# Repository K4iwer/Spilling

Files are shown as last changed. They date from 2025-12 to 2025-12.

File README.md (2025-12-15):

# Spilling 

**Spilling** (uma junção de "Spinning" e "Feeling") é um jogo sério híbrido (físico e digital) desenvolvido para auxiliar no desenvolvimento socioemocional e cognitivo de crianças com Transtorno do Espectro Autista (TEA).

Este projeto foi desenvolvido como parte da disciplina **PCS3645 - Laboratório Digital II** da Escola Politécnica da USP.

## Propósito do Projeto

A proposta central do Spilling é utilizar uma interface tangível para ensinar como personagens reagem a diferentes objetos e situações, transformando conceitos abstratos de empatia e causalidade em uma interação física concreta.

O jogo visa:
* **Estimular a Empatia:** A criança deve deduzir emoções baseadas em contexto.
* **Reforço Positivo:** O sistema prioriza o incentivo e evita punições, mantendo o engajamento.
* **Tangibilidade:** O uso de controles físicos promove a coordenação motora fina e oferece uma noção concreta de causa e efeito.

## Como Funciona

O sistema opera através da integração entre uma aplicação de software e uma estrutura de hardware (controlada por uma FPGA).

1.  **Lógica:** O jogo apresenta "equações emocionais" (ex: *Menino + Sorvete = Feliz*), imagens com contextos e "equações emocionais" omitindo elementos.
2.  **Interface Física:** O jogador utiliza suportes físicos para selecionar o Personagem, a Situação e a Emoção. Sensores de distância leem a escolha e enviam para o software.
3.  **Feedback:** A tela exibe animações de sucesso ou encorajamento, e a estrutura física responde girando discos para confirmar a seleção.

### A Interface Digital

A aplicação foi desenvolvida em **Python** utilizando a biblioteca **PyQt6**. Ela possui um design limpo, com cores suaves para evitar sobrecarga sensorial.

Funcionalidades da interface:
* **Menu Principal:** Opções para Iniciar Jogo, Configurar Porta Serial (para conexão com a FPGA), Tutorial e Personalização de Cor de Fundo.
* **Fases Progressivas:** 12 níveis que evoluem de associação direta para inferência lógica.
* **Feedback Visual:** Telas de vitória e mensagens de apoio ("Quase lá") em caso de erro.

---

## Imagens

### Estrutura Física
*(A estrutura conta com discos giratórios e base para seleção de peças via sensores ultrassônicos)*

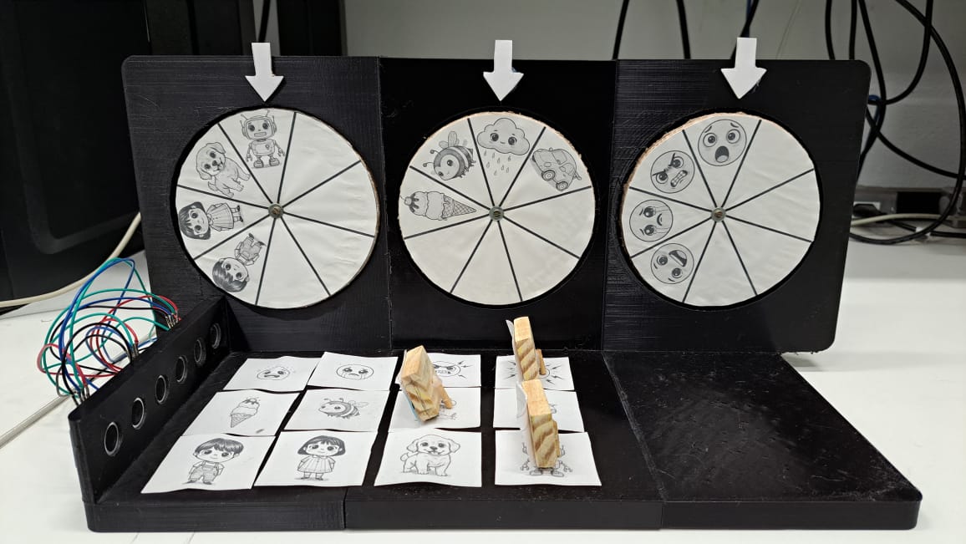
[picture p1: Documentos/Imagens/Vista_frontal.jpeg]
Estrutura Física do Spilling

> *Vista da bancada com os discos e a área de seleção.*

### Interface do Usuário

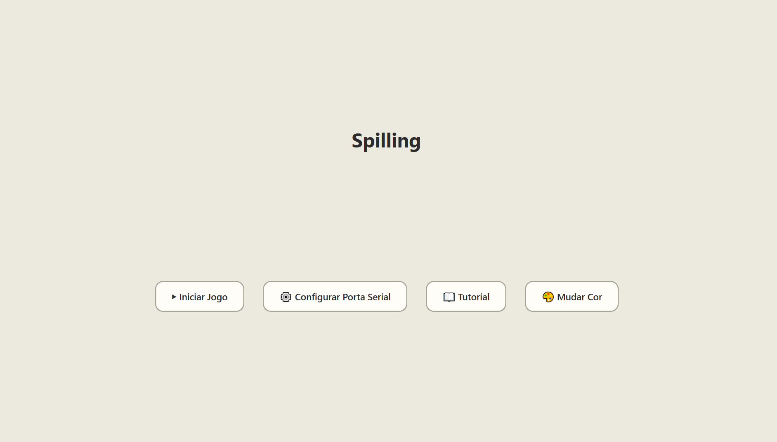
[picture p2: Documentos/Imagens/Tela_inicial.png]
Tela de Gameplay

> *Exemplo de fase: Associação de elementos.*

---

## Como Rodar a Aplicação

Para executar a interface do jogo em seu computador, siga os passos abaixo. É recomendado o uso de um ambiente virtual (`venv`) para gerenciar as dependências.

### Pré-requisitos
* Python 3.x instalado.

### Passo a Passo

1.  **Crie e ative o ambiente virtual (venv):**

    * *No Windows:*
        ```bash
        python -m venv venv
        .\venv\Scripts\activate
        ```
    * *No Linux/macOS:*
        ```bash
        python3 -m venv venv
        source venv/bin/activate
        ```

2.  **Instale as dependências:**
    *(Certifique-se de ter as bibliotecas `PyQt6` e `pyserial` instaladas)*
    ```bash
    pip install PyQt6 pyserial
    ```

3.  **Execute o jogo:**
    O arquivo principal está localizado dentro da pasta `Aplicação`.
    ```bash
    python Aplicação/main.py
    ```

> **Nota:** Para o funcionamento completo do jogo, a placa FPGA deve estar conectada via USB e a porta serial correta deve ser selecionada no menu de configurações ("Configurar Porta Serial"). No entanto, é possível abrir a interface gráfica para visualização mesmo sem o hardware conectado.

---

## 👨‍💻 Autores

* **Andrey Rocha Reboredo**
* **Caíque Cavalcante e Pachá**
* **Lucas Sposo Cavalari**

---
*Departamento de Engenharia de Computação e Sistemas Digitais (PCS) - POLI USP*

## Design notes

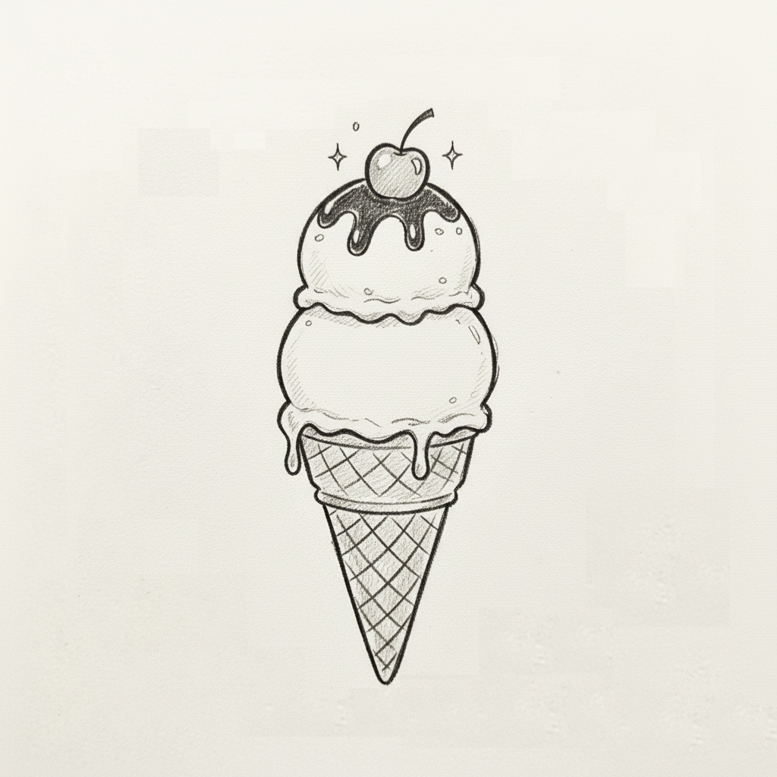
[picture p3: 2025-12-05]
Aplicação/assets/imagens/situacao/sorvete.png

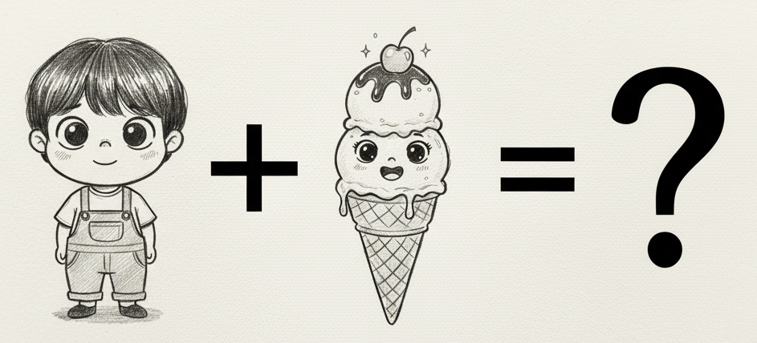
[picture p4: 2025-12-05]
Aplicação/assets/imagens/fases/fase9.png

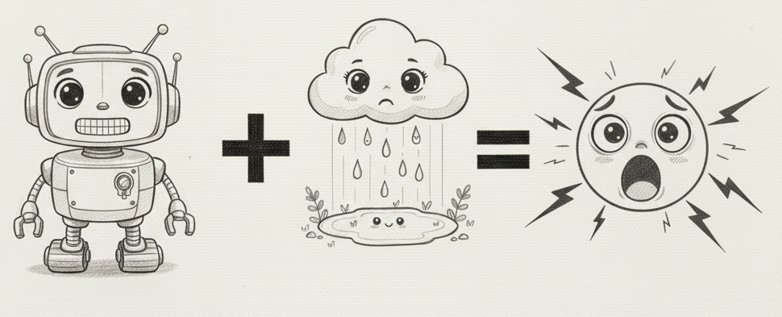
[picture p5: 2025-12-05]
Aplicação/assets/imagens/fases/fase4.png

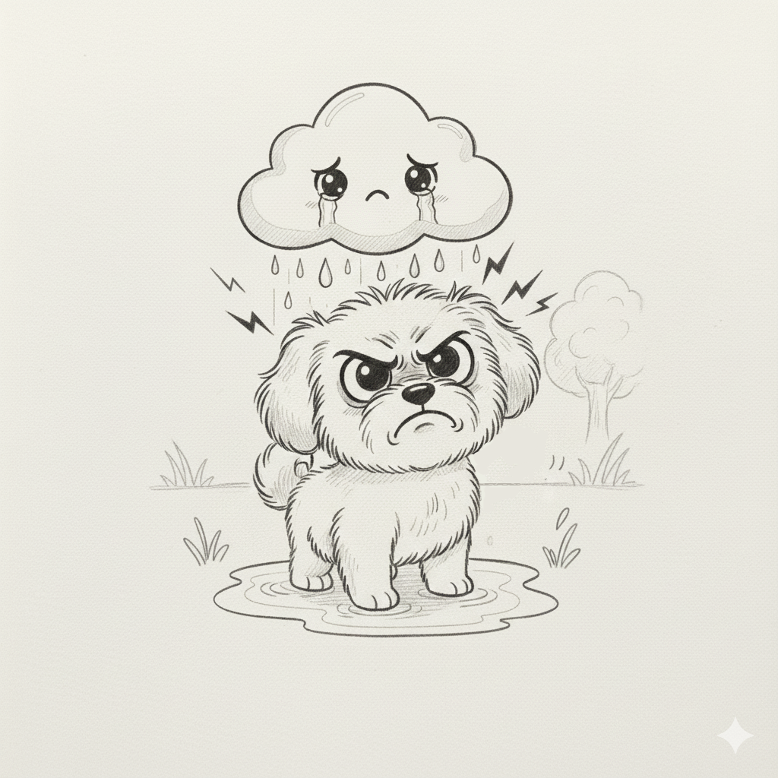
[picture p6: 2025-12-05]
Aplicação/assets/imagens/fases/fase7.png

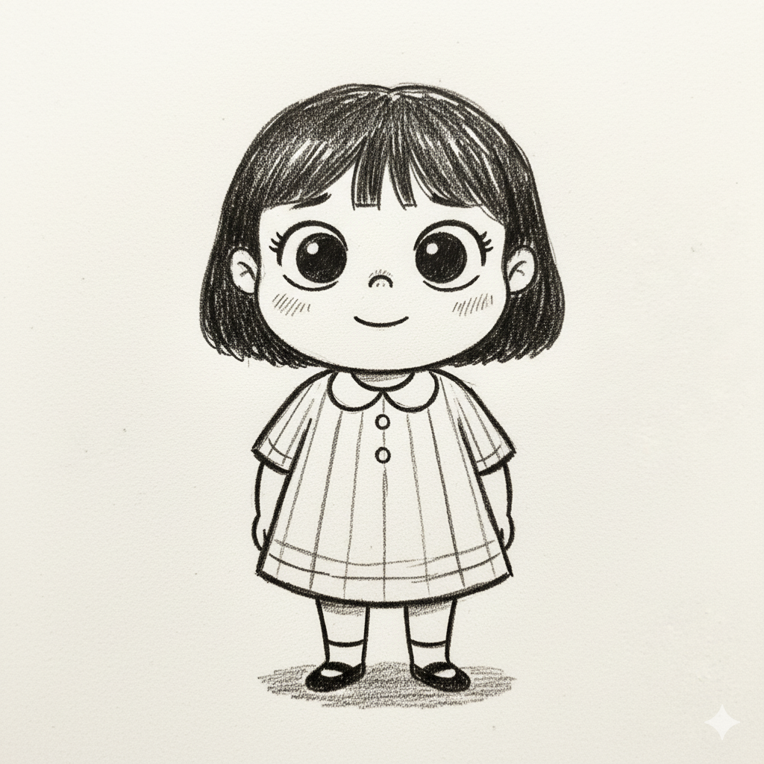
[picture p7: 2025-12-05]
Aplicação/assets/imagens/personagens/menina.png

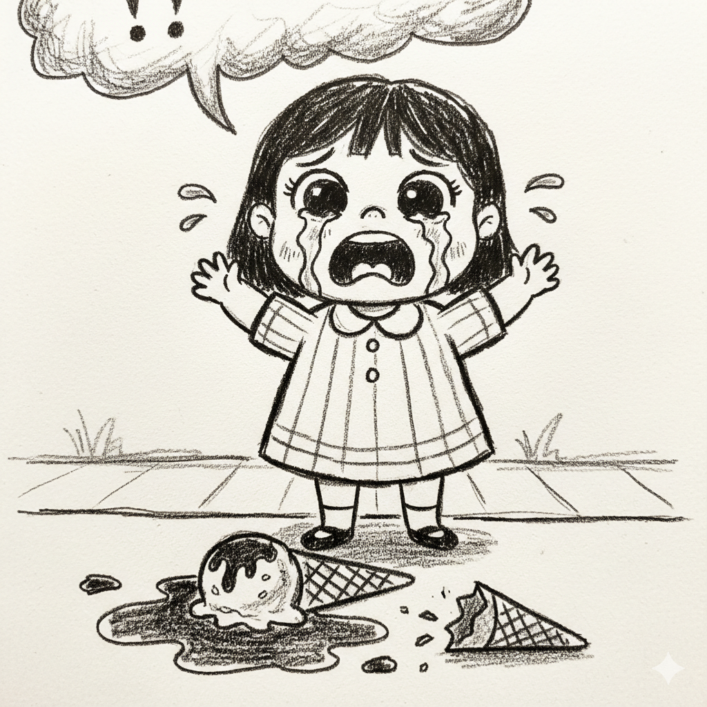
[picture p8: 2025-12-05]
Aplicação/assets/imagens/fases/fase6.png

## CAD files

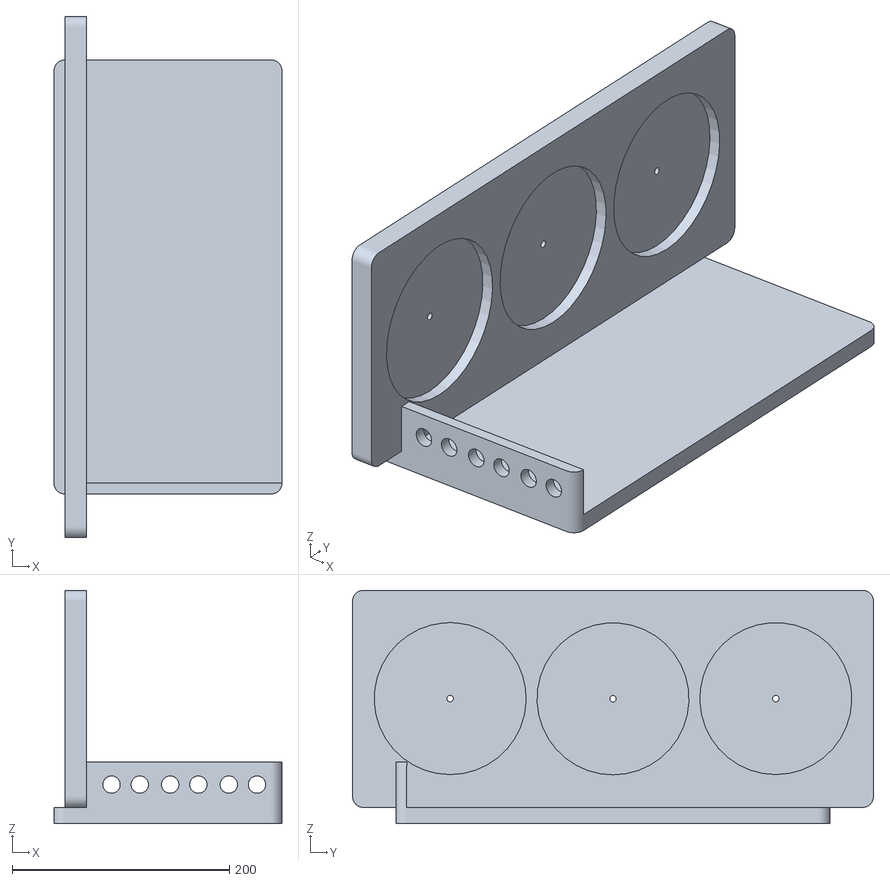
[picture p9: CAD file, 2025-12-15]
Documentos/Jogo peça principal.STL
210.0 x 480.0 x 215.0

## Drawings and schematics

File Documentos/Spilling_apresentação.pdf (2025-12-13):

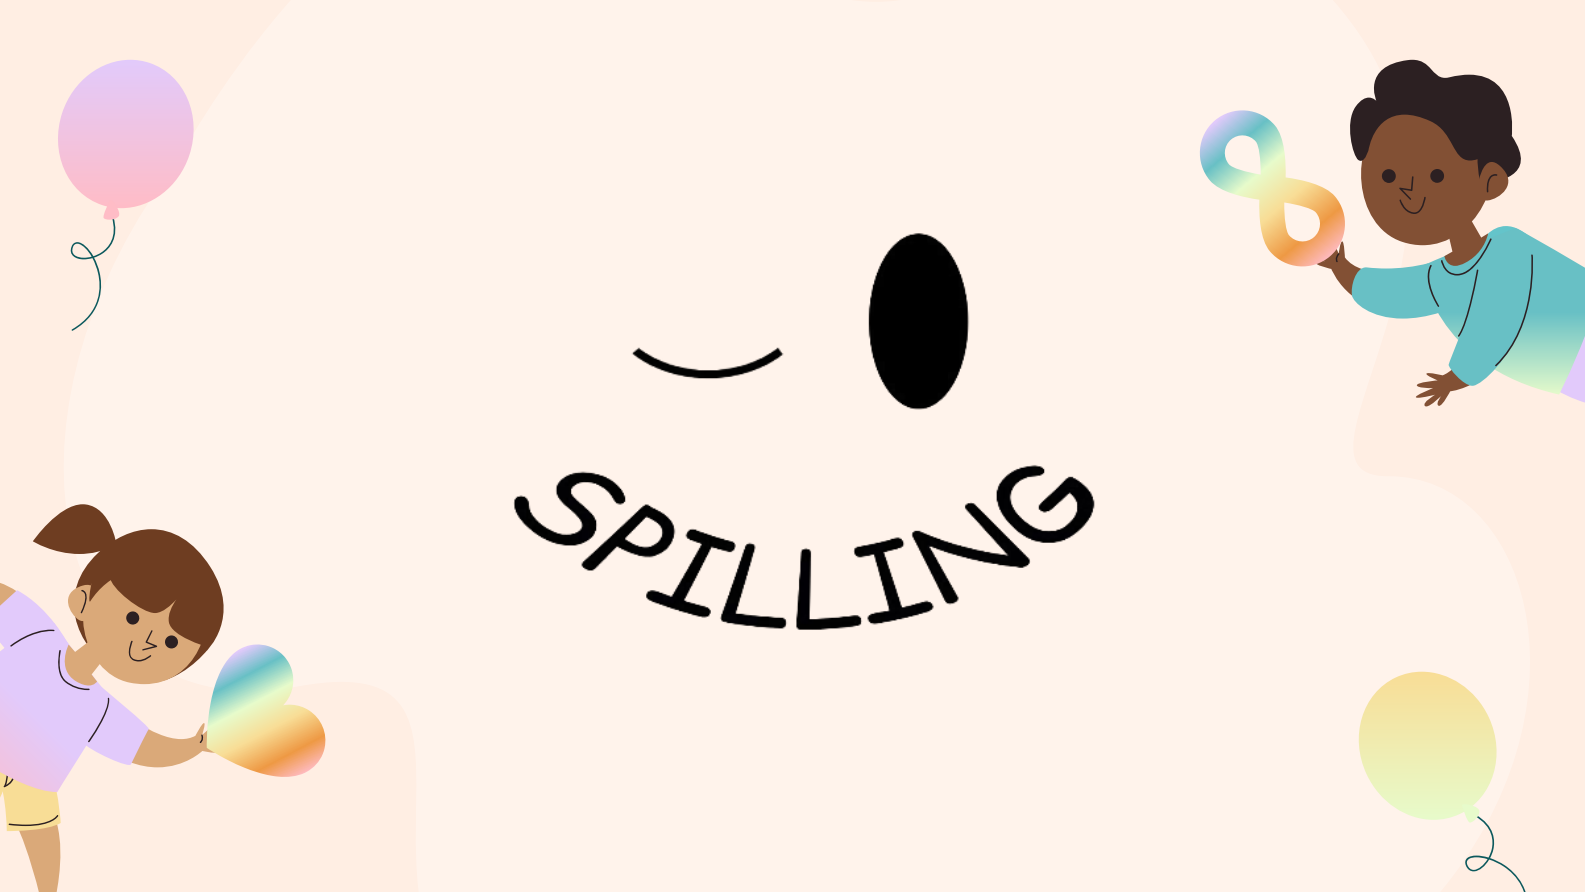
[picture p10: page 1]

# Como

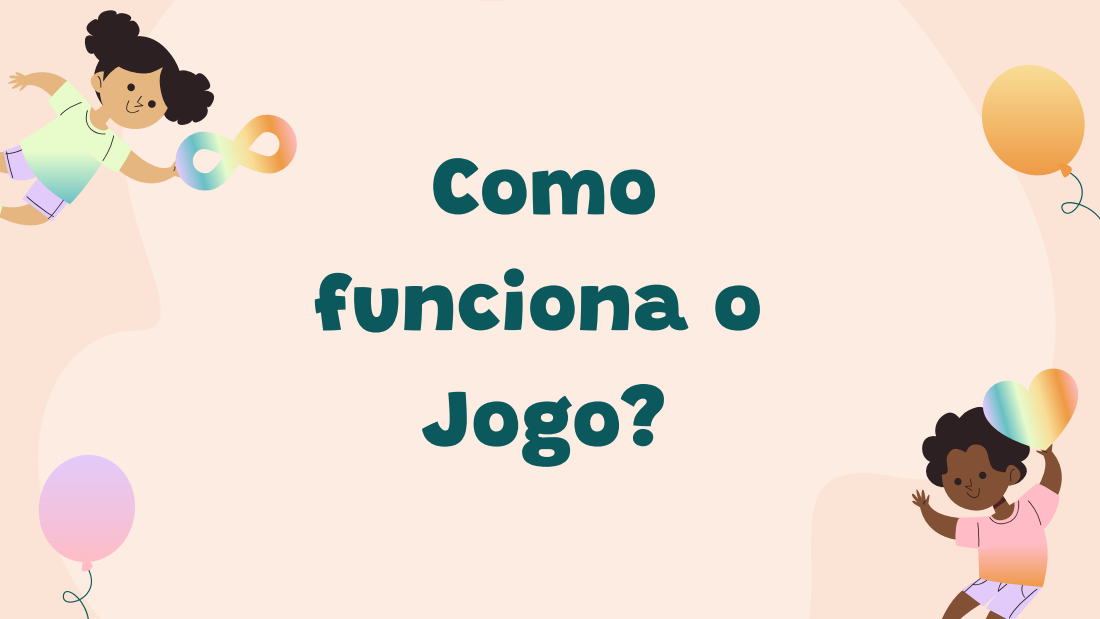
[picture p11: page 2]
funciona o Jogo?

Aplicação
apresenta
fase

Escolha das
opções

Computador apresenta
uma sequência com um
personagem, situação e
uma emoção

Giro dos discos
e check do nível
01 | 02 | 03

Escolha as opções que
acredita condizer com o
nível na montagem física

Discos apresentam a sua
jogada e o computador
checa se a resposta
escolhida está correta

## Descrição do Jogo

## Personagens

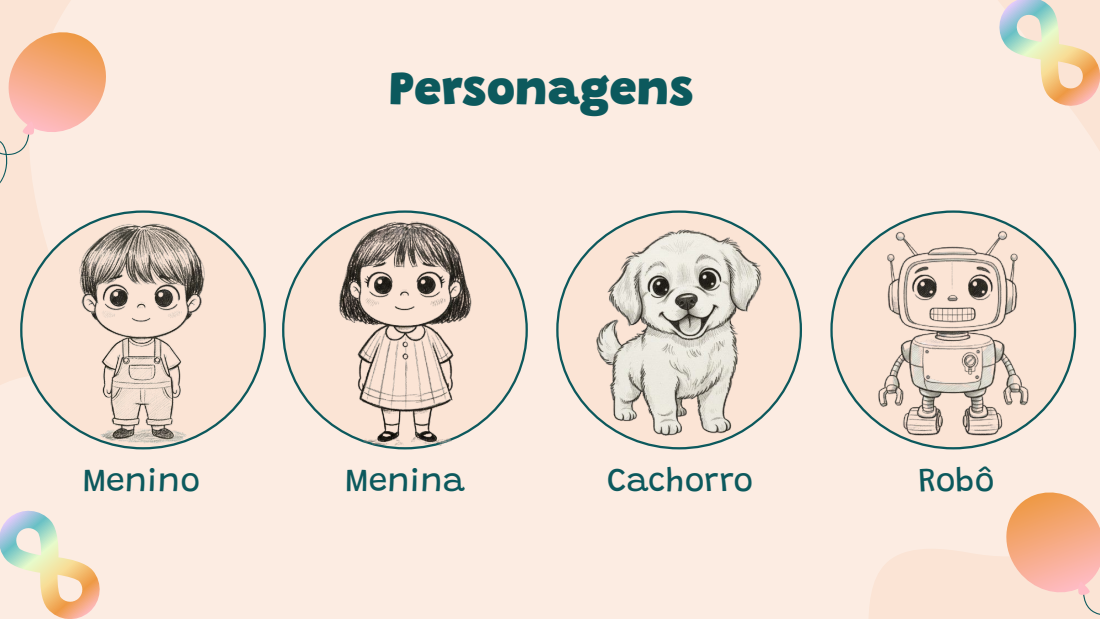
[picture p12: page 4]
Menino; Menina; Cachorro; Robô

## Situações

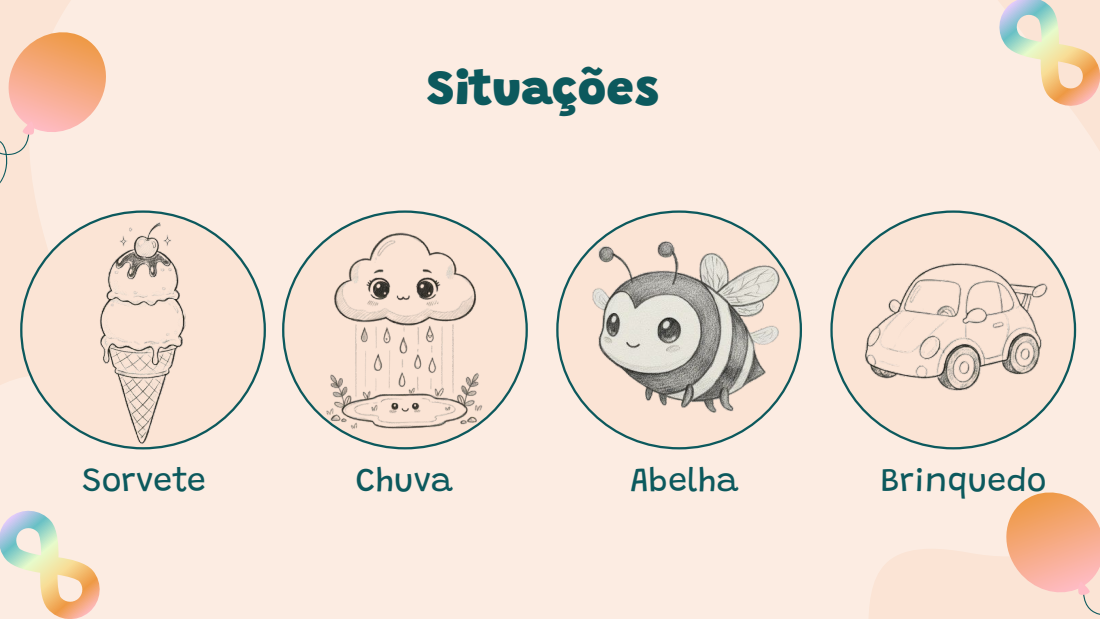
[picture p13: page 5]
Sorvete; Chuva; Abelha; Brinquedo

## Emoções

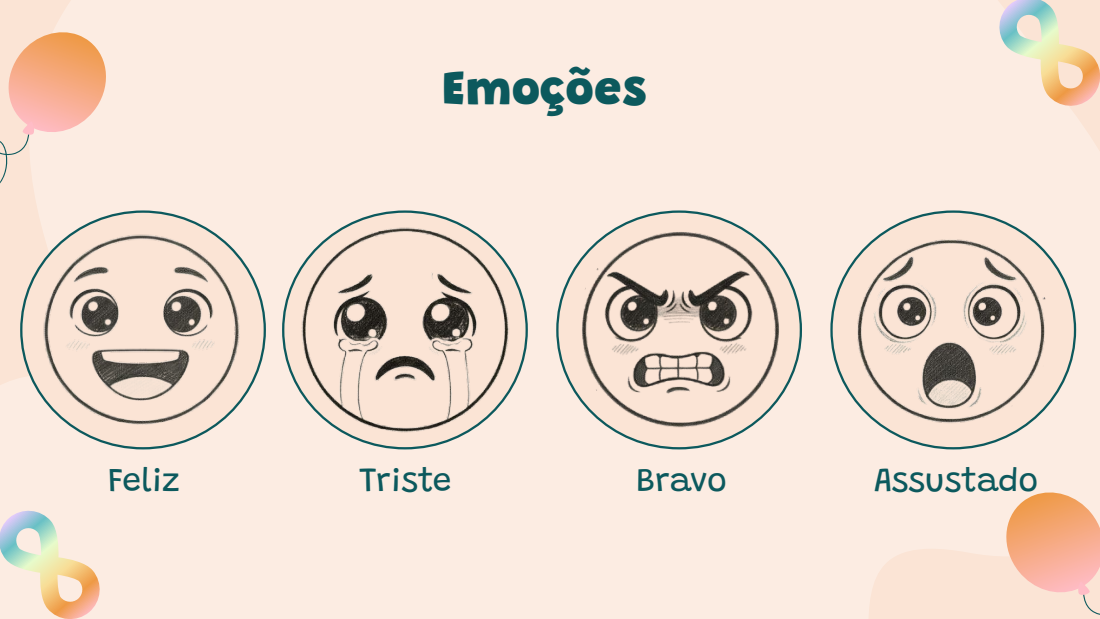
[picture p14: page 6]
Feliz; Triste; Bravo; Assustado

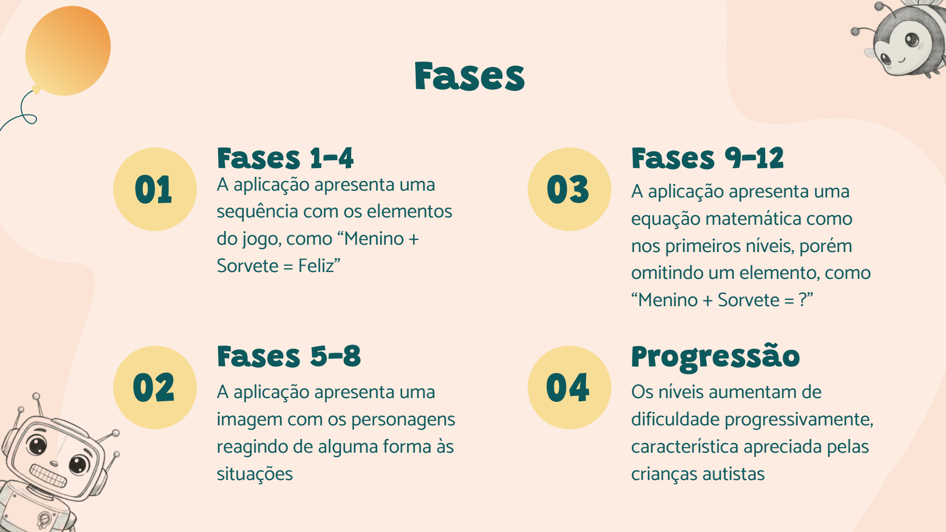
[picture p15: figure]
Fases; Fases 9-12 A aplicação apresenta uma equação matemática como nos primeiros níveis, porém omitindo um elemento, como “Menino + Sorvete = ?”; Progressão Os níveis aumentam de dificuldade progressivamente, característica apreciada pelas crianças autistas; Fases 1-4 A aplicação apresenta uma sequência com os elementos do jogo, como “Menino + Sorvete = Feliz”; Fases 5-8 A aplicação apresenta uma imagem com os personagens reagindo de alguma forma às situações

## Fase 1

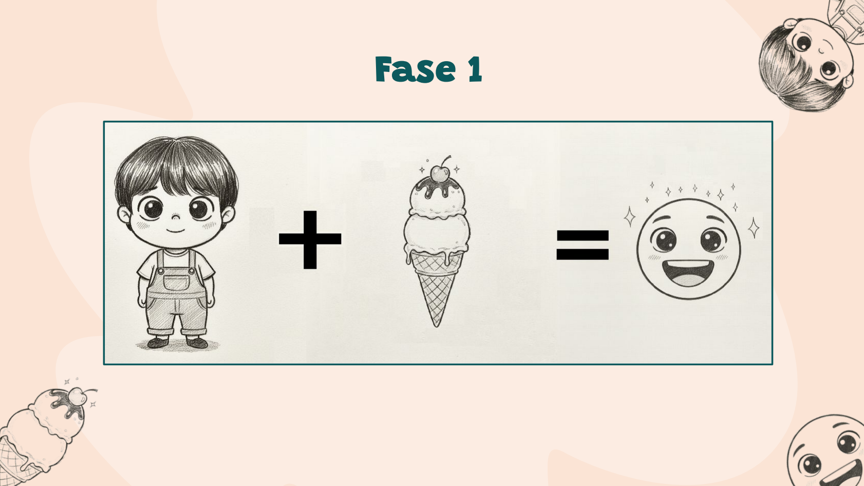
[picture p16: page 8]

## Fase 5

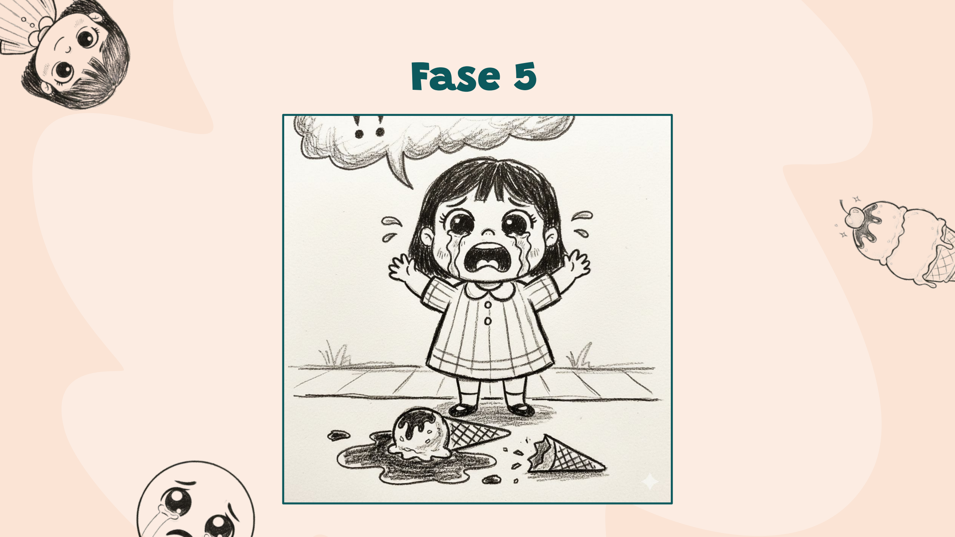
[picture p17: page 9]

## Fase 9

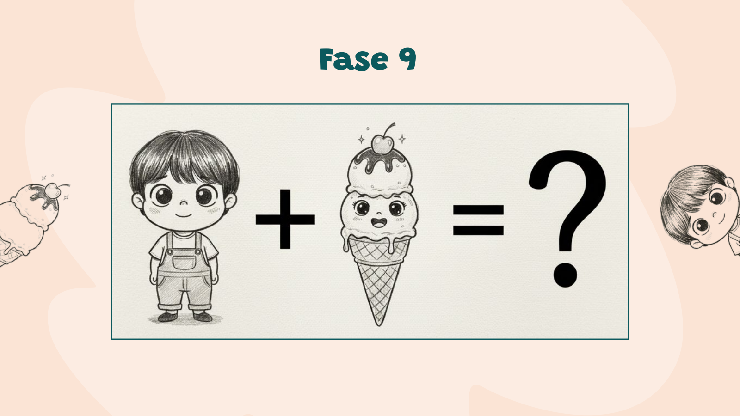
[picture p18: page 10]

## Adequação ao público alvo

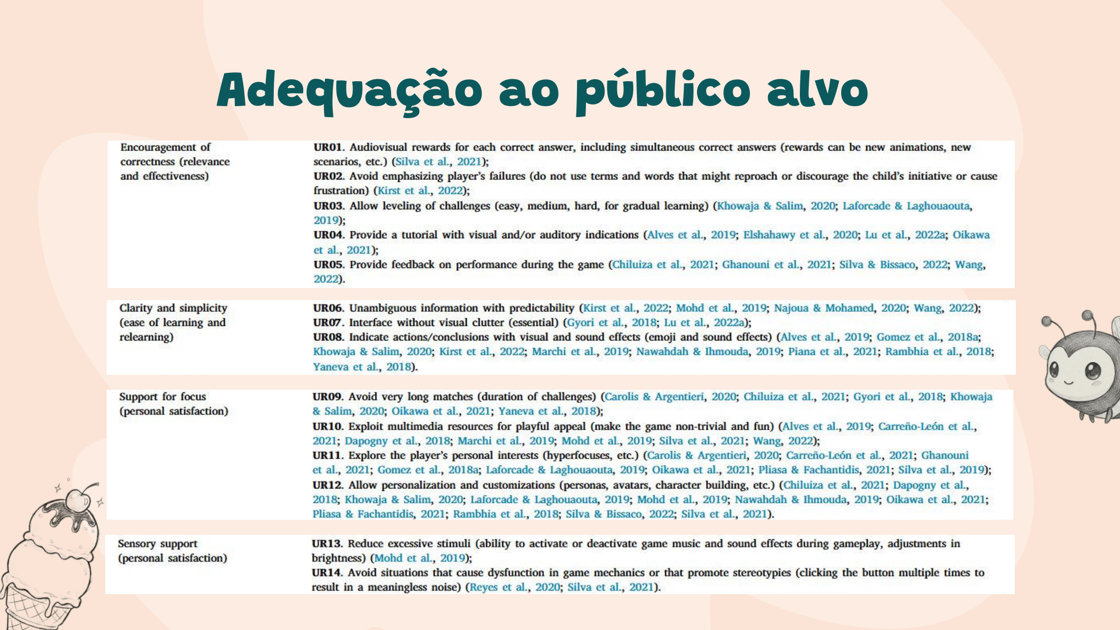
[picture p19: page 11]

## Propósito do Jogo

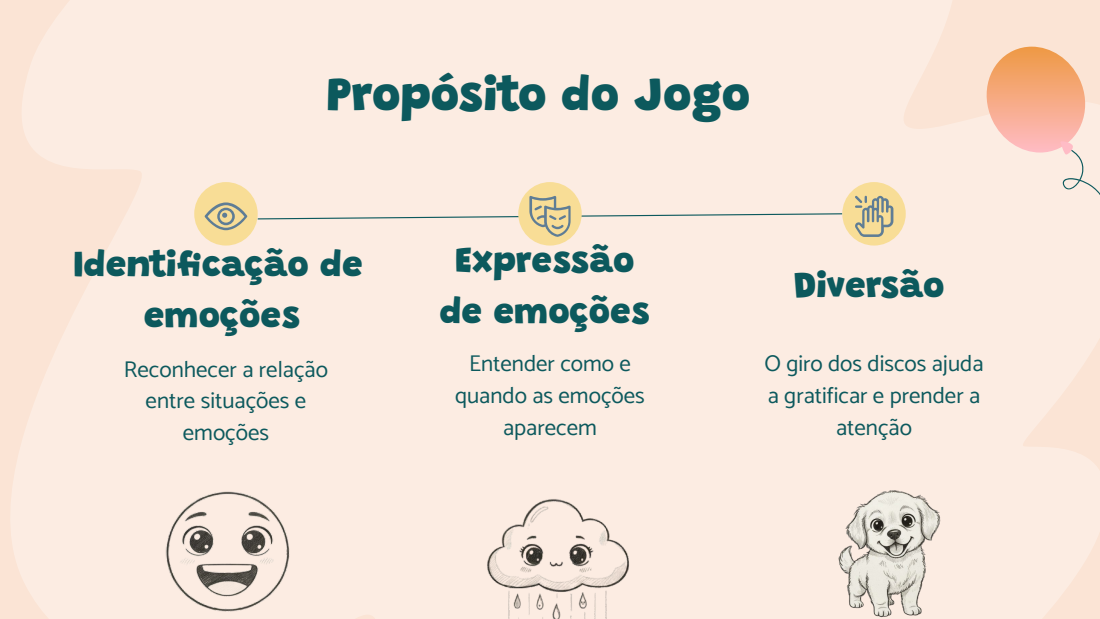
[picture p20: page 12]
Identificação de emoções; Expressão; de emoções; Diversão; Reconhecer a relação entre situações e emoções

Entender como e
quando as emoções
aparecem

O giro dos discos ajuda
a gratificar e prender a
atenção

## Pontos a melhorar

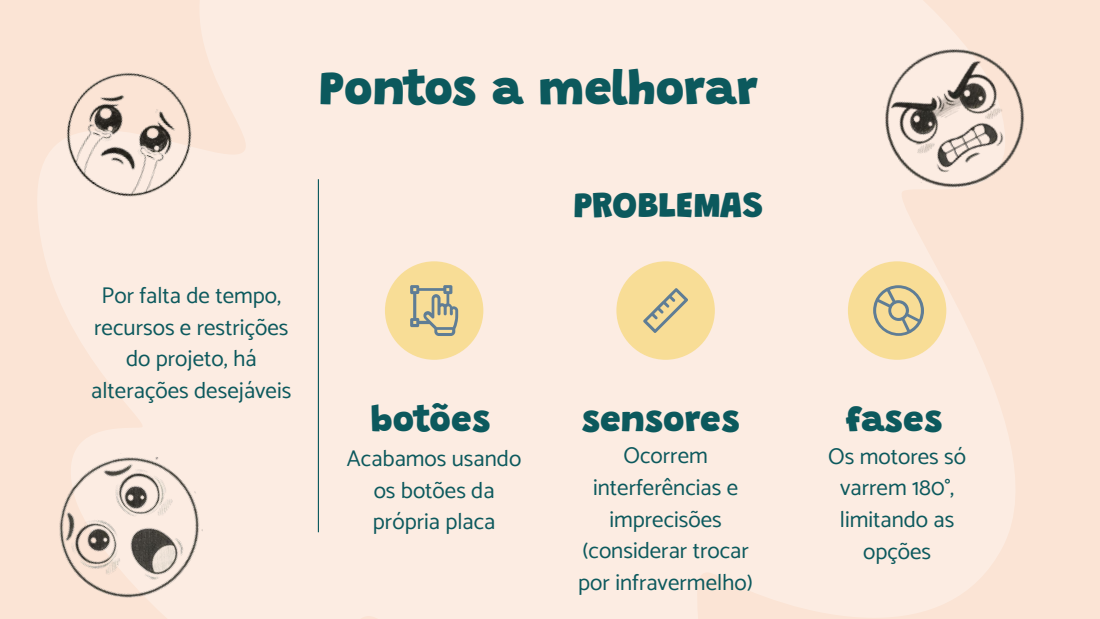
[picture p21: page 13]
sensores Ocorrem interferências e imprecisões (considerar trocar por infravermelho); PROBLEMAS

Por falta de tempo,
recursos e restrições
do projeto, há
alterações desejáveis

botões
Acabamos usando
os botões da
própria placa

fases
Os motores só
varrem 180°,
limitando as
opções

# Obrigado!


Modelo do slide utilizado do site SlidesGo, incluindo icones do Flaticon e imagens do Freepik

Caique Cavalcante e Pachá 13682934
Andrey Rocha Reboredo | 14558565
Lucas Sposo Cavalari | 14591733

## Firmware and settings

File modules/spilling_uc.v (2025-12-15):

module spilling_uc (
    input wire clock,
    input wire reset,
    input wire jogar,
    input wire pronto_seg,
    input wire [1:0] Q_2,
    input wire [1:0] Q_3,
    input wire pronto_serial,
    output reg cont_2,
    output reg cont_3,
    output reg zera_2,
    output reg zera_3,
    output reg partida_tx,
    output reg medir,
    output reg zera_sensor,
    output reg zera_serial,
    output reg zera_seg,
    output reg cont_seg,
    output reg zera_servos,
    output reg pronto,
    output reg zera_disc,
    output reg carrega_disc,
    output reg [3:0] db_estado
);

/******************* Estados **********************/ 
parameter inicial       = 4'b0000;
parameter est_reset     = 4'b0001; 
parameter est_medir     = 4'b0010;
parameter esp_seg       = 4'b0011;
parameter move_servos   = 4'b0100;
parameter envia         = 4'b0101;
parameter proxEnvio     = 4'b0110;
parameter proxSensor    = 4'b0111;
parameter est_final     = 4'b1000;

/******************* Variáveis de estado **********************/ 

reg [3:0] Eatual, Eprox;

/******************* Transição de estado **********************/ 

always @(posedge clock or posedge reset) begin
    if (reset)
        Eatual <= inicial;
    else
        Eatual <= Eprox; 
end

/******************* Lógica de próximo estado **********************/ 

always @* begin
    case (Eatual)
        inicial:        Eprox = jogar ? est_reset : inicial;
        est_reset:      Eprox = est_medir;
        est_medir:      Eprox = esp_seg;
        esp_seg:        Eprox = pronto_seg ? move_servos : esp_seg;
        move_servos:    Eprox = envia;
        envia:          Eprox = pronto_serial ? proxEnvio : envia;
        proxEnvio:      Eprox = (Q_3 == 2'b11) ? proxSensor : envia;
        proxSensor:     Eprox = (Q_2 == 2'b10) ? est_final : envia;
        est_final:      Eprox = inicial;
        default:        Eprox = inicial;
    endcase
end

/******************* Lógica de saída (Moore) **********************/ 

always @(*) begin
    zera_sensor = 1'b0;
    zera_serial = 1'b0;
    zera_seg = 1'b0;
    zera_2 = 1'b0;
    zera_3 = 1'b0;
    zera_servos = 1'b0;
    medir = 1'b0;
    partida_tx = 1'b0;
    cont_2 = 1'b0;
    cont_3 = 1'b0;
    cont_seg = 1'b0;
    pronto = 1'b0;
    zera_disc = 1'b0;
    carrega_disc = 1'b0;

    case (Eatual)
        est_reset: begin
            zera_sensor = 1'b1;
            zera_serial = 1'b1;
            zera_seg = 1'b1;
            zera_2 = 1'b1;
            zera_3 = 1'b1;
            zera_servos = 1'b1;
            zera_disc = 1'b1;
        end
        est_medir: begin
            medir = 1'b1;
        end
        esp_seg: begin 
            cont_seg = 1'b1;
        end
        move_servos: begin
            carrega_disc = 1'b1;
        end
        envia: begin
            partida_tx = 1'b1;
        end
        proxEnvio: begin
            cont_3 = 1'b1;
        end
        proxSensor: begin
            cont_2 = 1'b1;
            zera_3 = 1'b1;
        end
        est_final: begin
            zera_2 = 1'b1;
            pronto = 1'b1;
        end
    endcase

end

/******************* Saída de depuração (estados) **********************/ 
always @* begin
    case(Eatual)
        inicial:        db_estado = 4'b0000;
        reset:          db_estado = 4'b0001;
        est_medir:      db_estado = 4'b0010;
        esp_seg:        db_estado = 4'b0011;
        move_servos:    db_estado = 4'b0100;
        envia:          db_estado = 4'b0101;
        proxEnvio:      db_estado = 4'b0110;
        proxSensor:     db_estado = 4'b0111;
        est_final:      db_estado = 4'b1000;
        default:        db_estado = 4'b1111; // erro
    endcase
end

endmodule

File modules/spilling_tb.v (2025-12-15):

`timescale 1ns/1ns

module spilling_tb;
    reg clock;
    reg reset;
    reg ligar;
    reg echo1;
    reg echo2;
    reg echo3;
    wire trigger1;
    wire trigger2;
    wire trigger3;
    wire saida_serial;
    wire pronto;
    wire db_PWM1;
    wire db_PWM2;
    wire db_PWM3;

    parameter clockPeriod = 20; // Clock de 50MHz
    always # (clockPeriod/2) clock = ~clock;
    reg [31:0] casos_teste [0:7];
    integer i;

    // Variável para o período de um bit no protocolo 7E1
    real bit_period;

    spilling DUT (
        .clock(clock),
        .reset(reset),
        .ligar(ligar),
        .echo1(echo1),
        .echo2(echo2),
        .echo3(echo3),
        .trigger1(trigger1),
        .trigger2(trigger2),
        .trigger3(trigger3),
        .saida_serial(saida_serial),
        .pronto(pronto),
        .db_PWM1(db_PWM1),
        .db_PWM2(db_PWM2),
        .db_PWM3(db_PWM3)
    );

    initial begin
        $display("Inicio das simulacoes");
        casos_teste[0] = 411;  // 411us = 7cm, categoria 1 (00)
        casos_teste[1] = 706;  // 706us = 12cm, categoria 2 (01)
        casos_teste[2] = 1294;  // 1294us = 22cm, categoria 3 (10)
        casos_teste[3] = 1471;  // 1471us = 25cm, categoria 4 (11)
        // Define o período de um bit para o baud rate de 115000
        bit_period = 1_000_000_000 / 115200; // em nanosegundos

        // Valores iniciais
        clock = 0;
        reset = 1;
        ligar = 1;
        echo1 = 0;
        echo2 = 0;
        echo3 = 0;
        #20 reset = 0;  // Libera o reset após 20ns
        #100_000; // Espera 100us para início de operação

        for (i = 0; i < 4; i = i + 1) begin
            #(bit_period * 200);
            $display("Caso");
            #20 ligar = 1;
            #20 ligar = 0; // Liga o circuito

            wait(trigger1 == 1);
            #400_000; // tempo entre trigger e echo

            echo1 = 1; // Gera pulso Echo com largura definida no caso de teste
            echo2 = 1; // Gera pulso Echo com largura definida no caso de teste
            echo3 = 1; // Gera pulso Echo com largura definida no caso de teste
            #(casos_teste[i] * 1000);  // Converte microsegundos para nanosegundos
            echo1 = 0;
            echo2 = 0;
            echo3 = 0;

            #(bit_period * 2500);

            #(20_000_000); // espera o tempo do PMW
        end
        #100_000; 

        $stop; // Finaliza a simulação
    end

endmodule

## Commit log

2025-10-16 uc adicionados estados e começada lógica de transição
2025-10-16 uc terminada lógica de prox estado e começada lógica de saída
2025-10-18 UC acho que finalizada
2025-10-18 removidos sinais desnecessários na FD e UC, adicionado 'pronto' na UC, invertida a ordem de escolha nos muxs da FD e integração top level feita, faltando ajustar saídas de depuração
2025-10-27 comecei a fazer a aplicação, adicionei a conexão serial, sistemas de níveis e discretização
2025-10-28 Adição de tela de tutorial, feedback em caso de erro e barra de progresso q fala o nível
2025-10-31 adição de envio serial e tela de vitoria
2025-11-01 receptor serial alterado para 7E1 e junção com o projeto (alterada FD e UC). Talvez funcione mas precisa alterar a tb pra testar
2025-11-02 removido cópia de deslocador e comentado pra fora os displays hexa np módulo de recpção serial
2025-11-02 fix de algumas coisas q n estavam certas
    [roberto_uc.v]
2025-11-08 criado estado de reset no top level e adicionados módulos de controle do motor
    [roberto_uc.v]
2025-11-08 Ajustes no jogo para ter os níveis com fases reais
2025-11-08 criado enconder os dados recebidos entrarem no controlador do servo. Criados sinais de db
2025-11-09 teoricamente controle dos servos implementado, mas ta dando merda nos testes e é em algo da recepção serial
2025-12-13 Adição de imagens de documentação
2025-12-15 Ajustes finais dos servos (angulação dos discos) + do discretizador + alterado o nome para Spilling!
2025-12-15 Adicionado arquivo solid works da montagem física
    [Jogo peça principal.STL]
